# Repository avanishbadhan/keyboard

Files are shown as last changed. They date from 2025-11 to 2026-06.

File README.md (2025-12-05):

This project is a modular wired keyboard, consisting of a 75% keyboard with an attachable macropad. 
I made this project as a way to learn a variety of things including Schematic and PCB design, as it was my first time working with these; and also to practice some CAD. I have always wanted to know how keyboards work in general, as I use them every single day, and thought this might be a great way to learn, given the opportunity from Hack Club's Blueprint to bring my ideas to life.
Here are some images of CAD and PCB Design, BOM at the end.










|Item |Description |Quantity|Unit Price ($)|Total Price ($)|URL |Running Total ($ with Tax)|
|---|---|---|---|---|---|---|
|SOD-123 Switch Diodes |Switch Diodes (100pcs)|1 |1.28 |1.28 |https://www.aliexpress.us/item/3256807350544438.html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 |1.28 |
|Holy Panda Tactile Switches |MX Switches (110pcs)  |1 |33.3 |33.3 |https://www.aliexpress.us/item/3256805924985540.html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|34.58 |
|PJ-320D Headphone Jack |TRRS Jack (5pcs) |1 |1.04 |1.04 |https://www.aliexpress.us/item/3256808202284065.html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 |35.62 |
|Aux Stereo Cable |TRRS Cable |1 |3.58 |3.58 |https://www.aliexpress.us/item/3256805456527650.html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 |39.2 |
|Nice!Nano V2 Compatible Devboard |Devboard |1 |2.89 |2.89 |https://www.aliexpress.us/item/3256809330366531.html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 |42.09 |
|Arduino ProMicro Compatible Devboard|Devboard |1 |6.23 |6.23 |https://www.aliexpress.us/item/3256805885300100.html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 |48.32 |
|Keycaps |MX Keycaps (123pcs) |1 |11.33 |11.33 |https://www.aliexpress.us/item/3256808975886837.html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|59.65 |
|Solder Paste |Solder Paste (2pcs) |1 |8.11 |8.11 |https://www.aliexpress.us/item/3256806722346427.html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 |67.76 |
|Mounted Snap-In MX Stabilizers |MX Stabilizers |2 |3.88 |7.76 |https://www.aliexpress.us/item/3256808413621831.html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 |75.52 |
|M2 22mm Countersunk Screws |Screws (20pcs) |1 |2.02 |2.02 |https://www.aliexpress.us/item/3256808624582928.html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 |77.54 |
|Keyboard Gasket Foam Strip |Gasket Foam (20pcs) |1 |4.59 |4.59 |https://www.aliexpress.us/item/3256804614353215.html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 |82.13 |

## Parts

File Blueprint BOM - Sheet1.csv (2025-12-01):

Item | Description | Quantity | Unit Price ($) | Total Price ($) | URL | Running Total ($ with Tax)
SOD-123 Switch Diodes | Switch Diodes (100pcs) | 1 | 1.28 | 1.28 | https://www.aliexpress.us/item/3256807350544438.html?mp=1 | 1.28
Holy Panda Tactile Switches | MX Switches (110pcs) | 1 | 33.3 | 33.3 | https://www.aliexpress.us/item/3256805924985540.html?mp=1 | 34.58
PJ-320D Headphone Jack | TRRS Jack (5pcs) | 1 | 1.04 | 1.04 | https://www.aliexpress.us/item/3256808202284065.html?mp=1 | 35.62
Aux Stereo Cable | TRRS Cable | 1 | 3.58 | 3.58 | https://www.aliexpress.us/item/3256805456527650.html?mp=1 | 39.2
Nice!Nano V2 Compatible Devboard | Devboard | 1 | 2.89 | 2.89 | https://www.aliexpress.us/item/3256809330366531.html?mp=1 | 42.09
Arduino ProMicro Compatible Devboard | Devboard | 1 | 6.23 | 6.23 | https://www.aliexpress.us/item/3256805885300100.html?mp=1 | 48.32
Keycaps | MX Keycaps (123pcs) | 1 | 11.33 | 11.33 | https://www.aliexpress.us/item/3256808975886837.html?mp=1 | 59.65
Solder Paste | Solder Paste (2pcs) | 1 | 8.11 | 8.11 | https://www.aliexpress.us/item/3256806722346427.html?mp=1 | 67.76
Mounted Snap-In MX Stabilizers | MX Stabilizers | 2 | 3.88 | 7.76 | https://www.aliexpress.us/item/3256808413621831.html?mp=1 | 75.52
M2 22mm Countersunk Screws | Screws (20pcs) | 1 | 2.02 | 2.02 | https://www.aliexpress.us/item/3256808624582928.html?mp=1 | 77.54
Keyboard Gasket Foam Strip | Gasket Foam (20pcs) | 1 | 4.59 | 4.59 | https://www.aliexpress.us/item/3256804614353215.html?mp=1 | 82.13

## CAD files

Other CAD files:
75% keyboard/Keyboard.iam
75% keyboard/Keyboard_Case.ipt
75% keyboard/Keyboard_PCB.ipt
75% keyboard/Keyboard_Plate.ipt
75% keyboard/Keyboard_Tray.ipt

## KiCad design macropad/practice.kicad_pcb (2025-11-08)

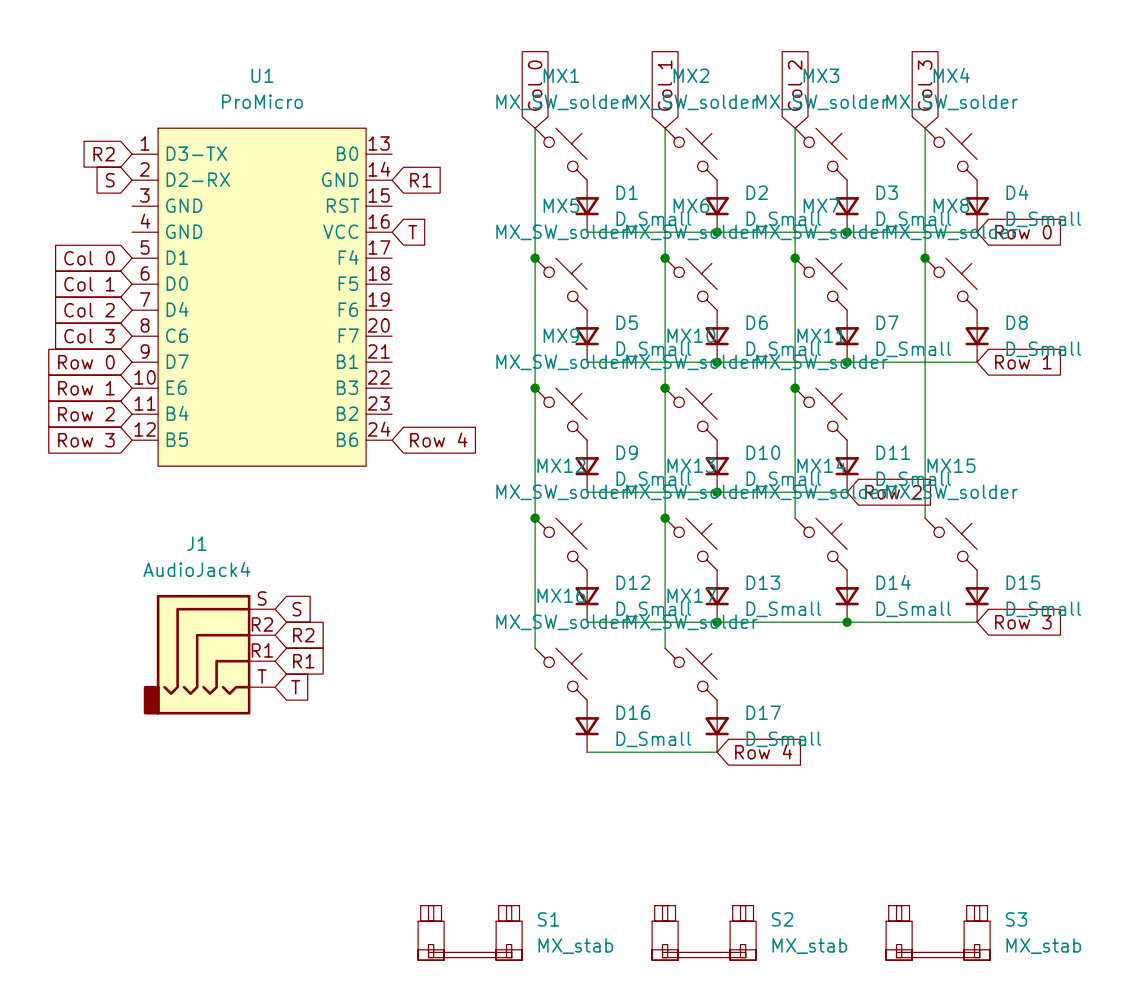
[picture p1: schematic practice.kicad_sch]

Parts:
D1, D2, D3, D4, D5, D6, D7, D8, D9, D10, D11, D12, D13, D14, D15, D16, D17: D_Small; D_SOD-123
J1: AudioJack4; Jack_3.5mm_PJ320D_Horizontal
MX1, MX2, MX3, MX4, MX5, MX6, MX7, MX8, MX9, MX10, MX11, MX12, MX13, MX14, MX15, MX16, MX17: MX_SW_solder; SW_MX_1u
S1, S2, S3: MX_stab; STAB_MX_2u
U1: ProMicro; ProMicro_USBup

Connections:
Col 0: MX1.1, MX5.1, MX9.1, MX12.1, MX16.1, U1.5 (D1)
Col 1: MX2.1, MX6.1, MX10.1, MX13.1, MX17.1, U1.6 (D0)
Col 2: MX3.1, MX7.1, MX11.1, MX14.1, U1.7 (D4)
Col 3: MX4.1, MX8.1, MX15.1, U1.8 (C6)
unnamed: D1.2 (A), MX1.2
unnamed: D2.2 (A), MX2.2
unnamed: D3.2 (A), MX3.2
unnamed: D4.2 (A), MX4.2
unnamed: D5.2 (A), MX5.2
unnamed: D6.2 (A), MX6.2
unnamed: D7.2 (A), MX7.2
unnamed: D8.2 (A), MX8.2
unnamed: D9.2 (A), MX9.2
unnamed: D10.2 (A), MX10.2
unnamed: D11.2 (A), MX11.2
unnamed: D12.2 (A), MX12.2
unnamed: D13.2 (A), MX13.2
unnamed: D14.2 (A), MX14.2
unnamed: D15.2 (A), MX15.2
unnamed: D16.2 (A), MX16.2
unnamed: D17.2 (A), MX17.2
R1: J1.R1, U1.14 (GND)
R2: J1.R2, U1.1 (D3-TX)
Row 0: D1.1 (K), D2.1 (K), D3.1 (K), D4.1 (K), U1.9 (D7)
Row 1: D5.1 (K), D6.1 (K), D7.1 (K), D8.1 (K), U1.10 (E6)
Row 2: D9.1 (K), D10.1 (K), D11.1 (K), U1.11 (B4)
Row 3: D12.1 (K), D13.1 (K), D14.1 (K), D15.1 (K), U1.12 (B5)
Row 4: D16.1 (K), D17.1 (K), U1.24 (B6)
S: J1.S, U1.2 (D2-RX)
T: J1.T, U1.16 (VCC)

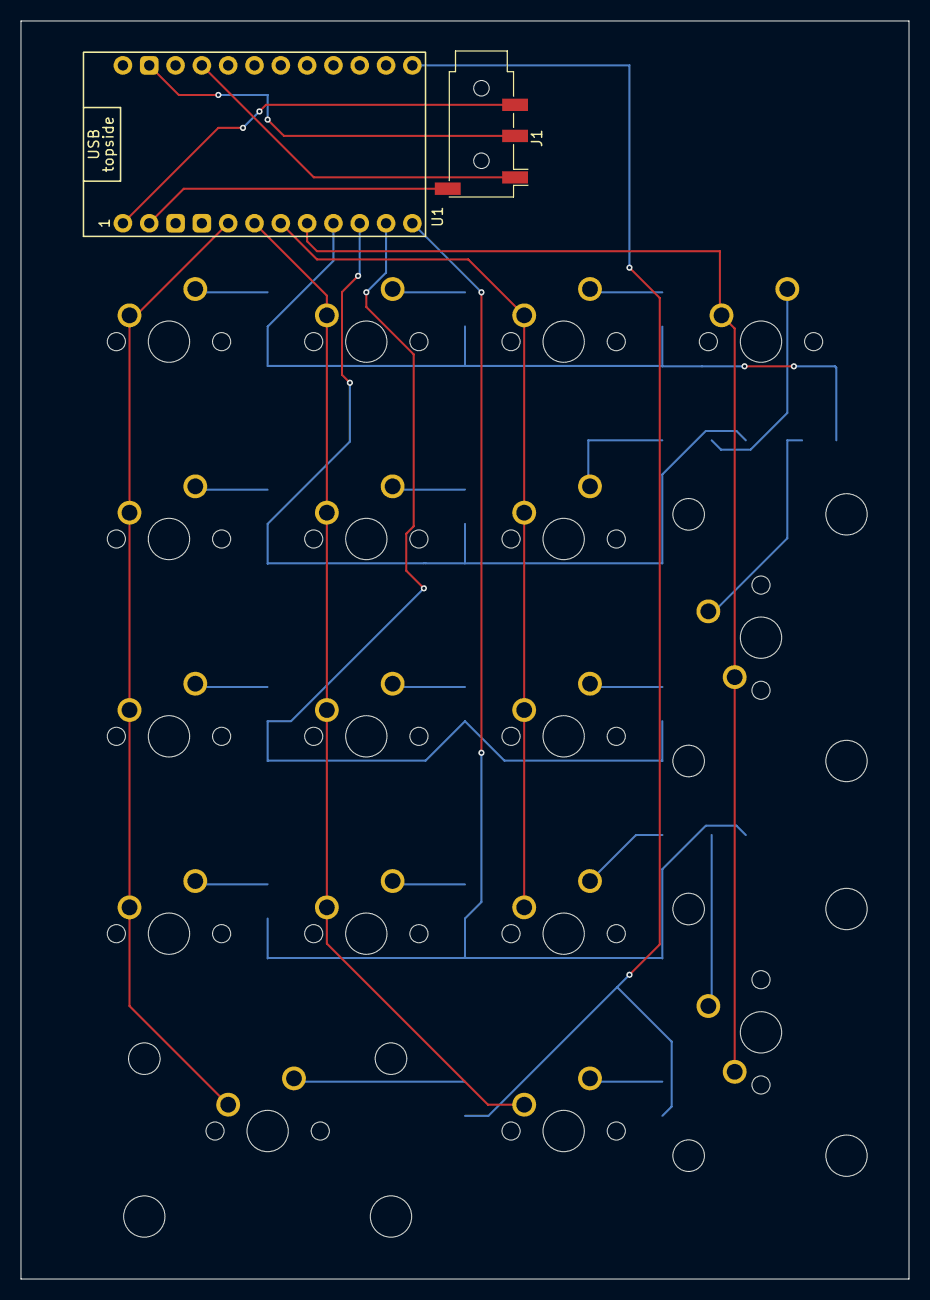
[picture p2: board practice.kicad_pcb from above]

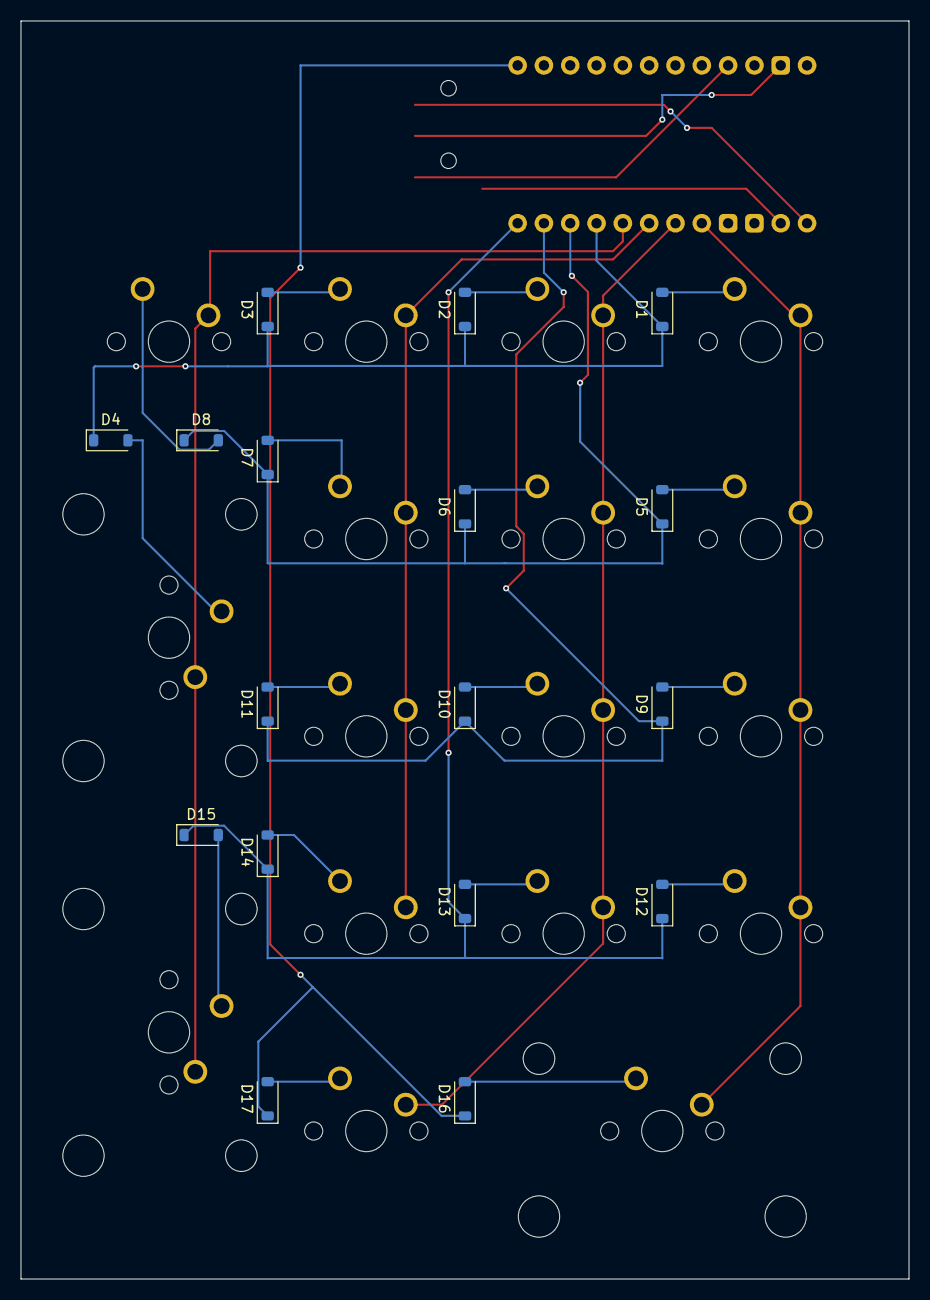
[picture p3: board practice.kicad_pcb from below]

Board: 2 copper layers, 85.7 x 121.4 mm, 39 parts (17 on the bottom side), 30 nets.

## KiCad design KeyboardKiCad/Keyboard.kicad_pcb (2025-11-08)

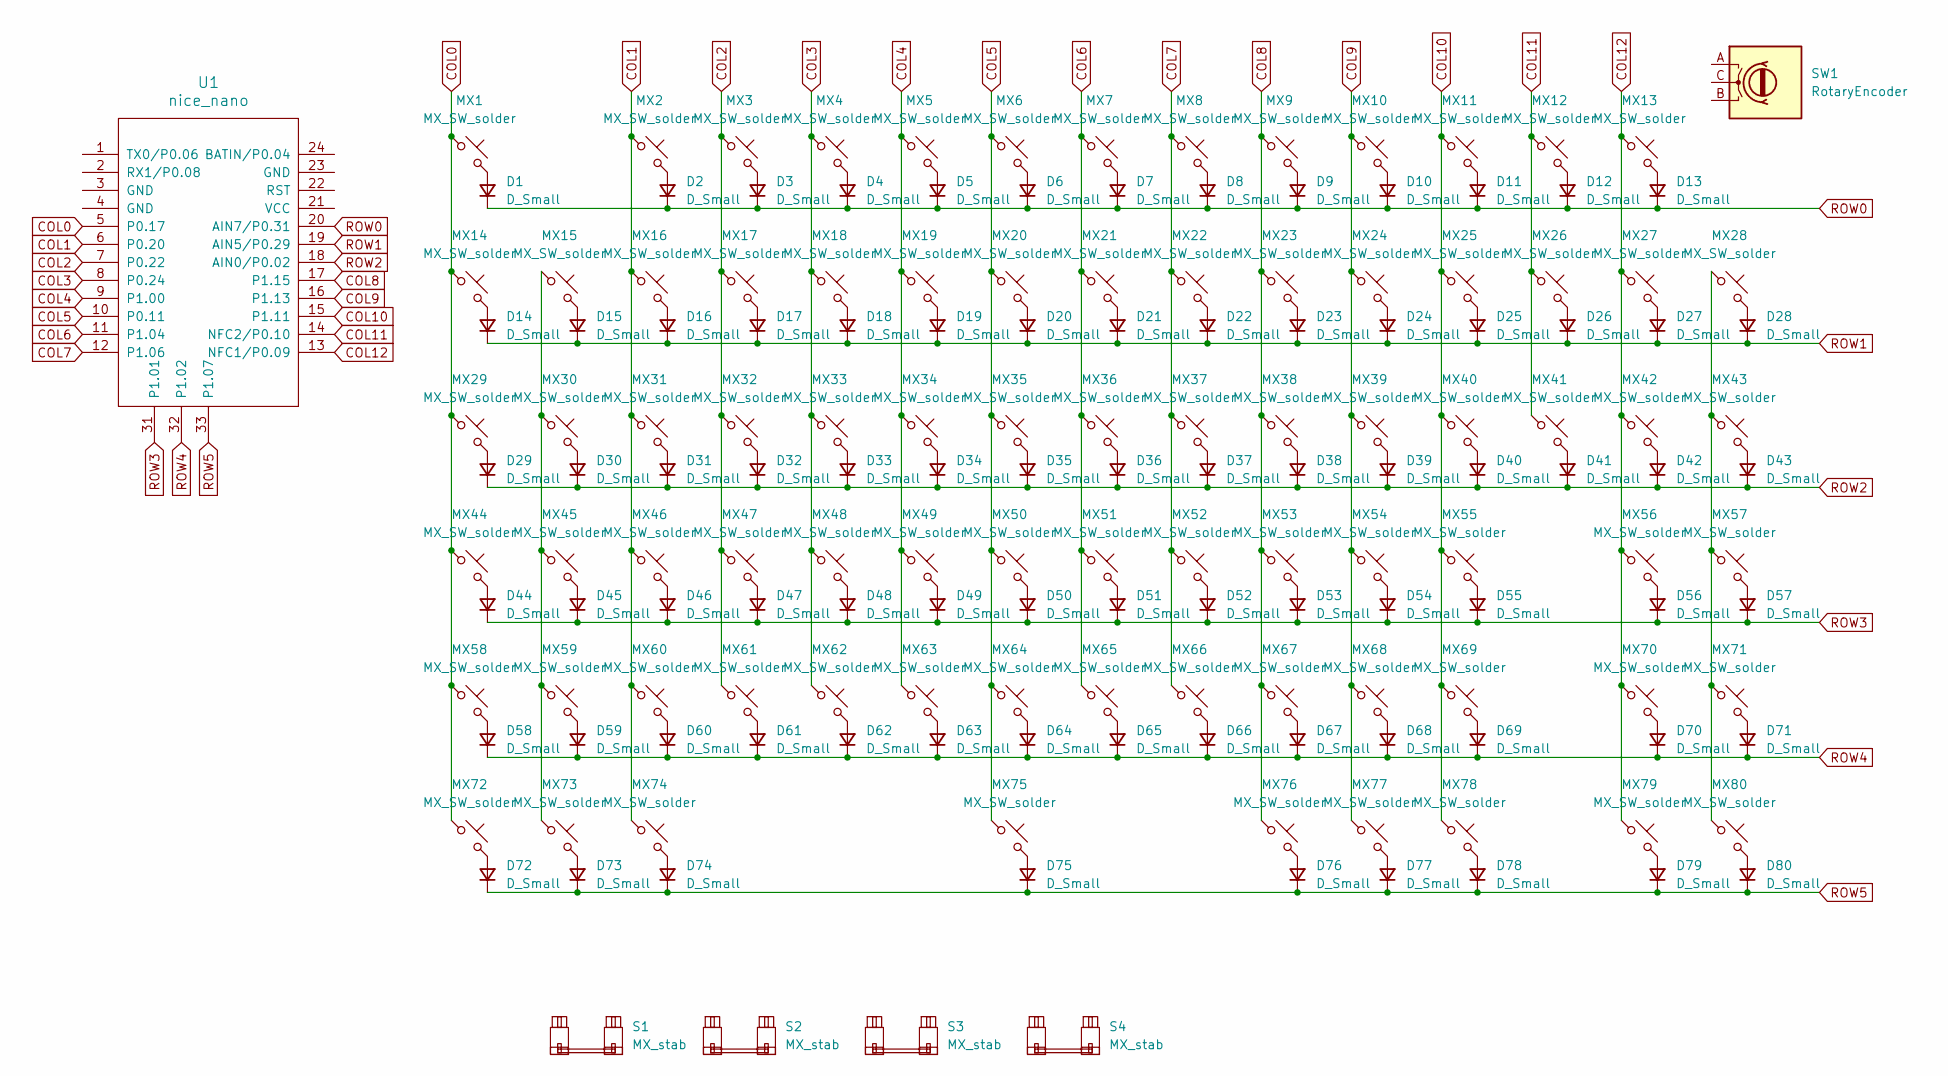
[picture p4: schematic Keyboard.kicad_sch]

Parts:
D1, D2, D3, D4, D5, D6, D7, D8, D9, D10, D11, D12, D13, D14, D15, D16, D17, D18, D19, D20, D21, D22, D23, D24, D25, D26, D27, D28, D29, D30, D31, D32, D33, D34, D35, D36, D37, D38, D39, D40, D41, D42, D43, D44, D45, D46, D47, D48, D49, D50, D51, D52, D53, D54, D55, D56, D57, D58, D59, D60, D61, D62, D63, D64, D65, D66, D67, D68, D69, D70, D71, D72, D73, D74, D75, D76, D77, D78, D79, D80: D_Small; D_SOD-123
MX1, MX2, MX3, MX4, MX5, MX6, MX7, MX8, MX9, MX10, MX11, MX12, MX13, MX14, MX15, MX16, MX17, MX18, MX19, MX20, MX21, MX22, MX23, MX24, MX25, MX26, MX27, MX28, MX30, MX31, MX32, MX33, MX34, MX35, MX36, MX37, MX38, MX39, MX40, MX41, MX43, MX45, MX46, MX47, MX48, MX49, MX50, MX51, MX52, MX53, MX54, MX55, MX56, MX57, MX58, MX59, MX60, MX61, MX62, MX63, MX64, MX65, MX66, MX67, MX68, MX70, MX71, MX75, MX78, MX79, MX80: MX_SW_solder; SW_MX_1u
MX29, MX42: MX_SW_solder; SW_MX_1.5u
MX44, MX69: MX_SW_solder; SW_MX_1.75u
MX72, MX73, MX74, MX76, MX77: MX_SW_solder; SW_MX_1.25u
S1: MX_stab; STAB_MX_P_2u
S2, S3: MX_stab; STAB_MX_P_2.25u
S4: MX_stab; STAB_MX_P_6.25u
SW1: RotaryEncoder; Bourns-PEC11R-4220F-S0024-0-0-0
U1: nice_nano; nice_nano_AH_Reversible

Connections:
COL0: MX1.1, MX14.1, MX29.1, MX44.1, MX58.1, MX72.1, U1.5 (P0.17)
COL1: MX2.1, MX16.1, MX31.1, MX46.1, MX60.1, MX74.1, U1.6 (P0.20)
COL2: MX3.1, MX17.1, MX32.1, MX47.1, MX61.1, U1.7 (P0.22)
COL3: MX4.1, MX18.1, MX33.1, MX48.1, MX62.1, U1.8 (P0.24)
COL4: MX5.1, MX19.1, MX34.1, MX49.1, MX63.1, U1.9 (P1.00)
COL5: MX6.1, MX20.1, MX35.1, MX50.1, MX64.1, MX75.1, U1.10 (P0.11)
COL6: MX7.1, MX21.1, MX36.1, MX51.1, MX65.1, U1.11 (P1.04)
COL7: MX8.1, MX22.1, MX37.1, MX52.1, MX66.1, U1.12 (P1.06)
COL8: MX9.1, MX23.1, MX38.1, MX53.1, MX67.1, MX76.1, U1.17 (P1.15)
COL9: MX10.1, MX24.1, MX39.1, MX54.1, MX68.1, MX77.1, U1.16 (P1.13)
COL10: MX11.1, MX25.1, MX40.1, MX55.1, MX69.1, MX78.1, U1.15 (P1.11)
COL11: MX12.1, MX26.1, MX41.1, U1.14 (NFC2/P0.10)
COL12: MX13.1, MX27.1, MX42.1, MX56.1, MX70.1, MX79.1, U1.13 (NFC1/P0.09)
unnamed: D1.2 (A), MX1.2
unnamed: D2.2 (A), MX2.2
unnamed: D3.2 (A), MX3.2
unnamed: D4.2 (A), MX4.2
unnamed: D5.2 (A), MX5.2
unnamed: D6.2 (A), MX6.2
unnamed: D7.2 (A), MX7.2
unnamed: D8.2 (A), MX8.2
unnamed: D9.2 (A), MX9.2
unnamed: D10.2 (A), MX10.2
unnamed: D11.2 (A), MX11.2
unnamed: D12.2 (A), MX12.2
unnamed: D13.2 (A), MX13.2
unnamed: D14.2 (A), MX14.2
unnamed: D15.2 (A), MX15.2
unnamed: D16.2 (A), MX16.2
unnamed: D17.2 (A), MX17.2
unnamed: D18.2 (A), MX18.2
unnamed: D19.2 (A), MX19.2
unnamed: D20.2 (A), MX20.2
unnamed: D21.2 (A), MX21.2
unnamed: D22.2 (A), MX22.2
unnamed: D23.2 (A), MX23.2
unnamed: D24.2 (A), MX24.2
unnamed: D25.2 (A), MX25.2
unnamed: D26.2 (A), MX26.2
unnamed: D27.2 (A), MX27.2
unnamed: D28.2 (A), MX28.2
unnamed: D29.2 (A), MX29.2
unnamed: D30.2 (A), MX30.2
unnamed: D31.2 (A), MX31.2
unnamed: D32.2 (A), MX32.2
unnamed: D33.2 (A), MX33.2
unnamed: D34.2 (A), MX34.2
unnamed: D35.2 (A), MX35.2
unnamed: D36.2 (A), MX36.2
unnamed: D37.2 (A), MX37.2
unnamed: D38.2 (A), MX38.2
unnamed: D39.2 (A), MX39.2
unnamed: D40.2 (A), MX40.2
unnamed: D41.2 (A), MX41.2
unnamed: D42.2 (A), MX42.2
unnamed: D43.2 (A), MX43.2
unnamed: D44.2 (A), MX44.2
unnamed: D45.2 (A), MX45.2
unnamed: D46.2 (A), MX46.2
unnamed: D47.2 (A), MX47.2
unnamed: D48.2 (A), MX48.2
unnamed: D49.2 (A), MX49.2
unnamed: D50.2 (A), MX50.2
unnamed: D51.2 (A), MX51.2
unnamed: D52.2 (A), MX52.2
unnamed: D53.2 (A), MX53.2
unnamed: D54.2 (A), MX54.2
unnamed: D55.2 (A), MX55.2
unnamed: D56.2 (A), MX56.2
unnamed: D57.2 (A), MX57.2
unnamed: D58.2 (A), MX58.2
unnamed: D59.2 (A), MX59.2
unnamed: D60.2 (A), MX60.2
unnamed: D61.2 (A), MX61.2
unnamed: D62.2 (A), MX62.2
unnamed: D63.2 (A), MX63.2
unnamed: D64.2 (A), MX64.2
unnamed: D65.2 (A), MX65.2
unnamed: D66.2 (A), MX66.2
unnamed: D67.2 (A), MX67.2
unnamed: D68.2 (A), MX68.2
unnamed: D69.2 (A), MX69.2
unnamed: D70.2 (A), MX70.2
unnamed: D71.2 (A), MX71.2
unnamed: D72.2 (A), MX72.2
unnamed: D73.2 (A), MX73.2
unnamed: D74.2 (A), MX74.2
unnamed: D75.2 (A), MX75.2
unnamed: D76.2 (A), MX76.2
unnamed: D77.2 (A), MX77.2
unnamed: D78.2 (A), MX78.2
unnamed: D79.2 (A), MX79.2
unnamed: D80.2 (A), MX80.2
unnamed: MX15.1, MX30.1, MX45.1, MX59.1, MX73.1
unnamed: MX28.1, MX43.1, MX57.1, MX71.1, MX80.1
ROW0: D1.1 (K), D2.1 (K), D3.1 (K), D4.1 (K), D5.1 (K), D6.1 (K), D7.1 (K), D8.1 (K), D9.1 (K), D10.1 (K), D11.1 (K), D12.1 (K), D13.1 (K), U1.20 (AIN7/P0.31)
ROW1: D14.1 (K), D15.1 (K), D16.1 (K), D17.1 (K), D18.1 (K), D19.1 (K), D20.1 (K), D21.1 (K), D22.1 (K), D23.1 (K), D24.1 (K), D25.1 (K), D26.1 (K), D27.1 (K), D28.1 (K), U1.19 (AIN5/P0.29)
ROW2: D29.1 (K), D30.1 (K), D31.1 (K), D32.1 (K), D33.1 (K), D34.1 (K), D35.1 (K), D36.1 (K), D37.1 (K), D38.1 (K), D39.1 (K), D40.1 (K), D41.1 (K), D42.1 (K), D43.1 (K), U1.18 (AIN0/P0.02)
ROW3: D44.1 (K), D45.1 (K), D46.1 (K), D47.1 (K), D48.1 (K), D49.1 (K), D50.1 (K), D51.1 (K), D52.1 (K), D53.1 (K), D54.1 (K), D55.1 (K), D56.1 (K), D57.1 (K), U1.31 (P1.01)
ROW4: D58.1 (K), D59.1 (K), D60.1 (K), D61.1 (K), D62.1 (K), D63.1 (K), D64.1 (K), D65.1 (K), D66.1 (K), D67.1 (K), D68.1 (K), D69.1 (K), D70.1 (K), D71.1 (K), U1.32 (P1.02)
ROW5: D72.1 (K), D73.1 (K), D74.1 (K), D75.1 (K), D76.1 (K), D77.1 (K), D78.1 (K), D79.1 (K), D80.1 (K), U1.33 (P1.07)

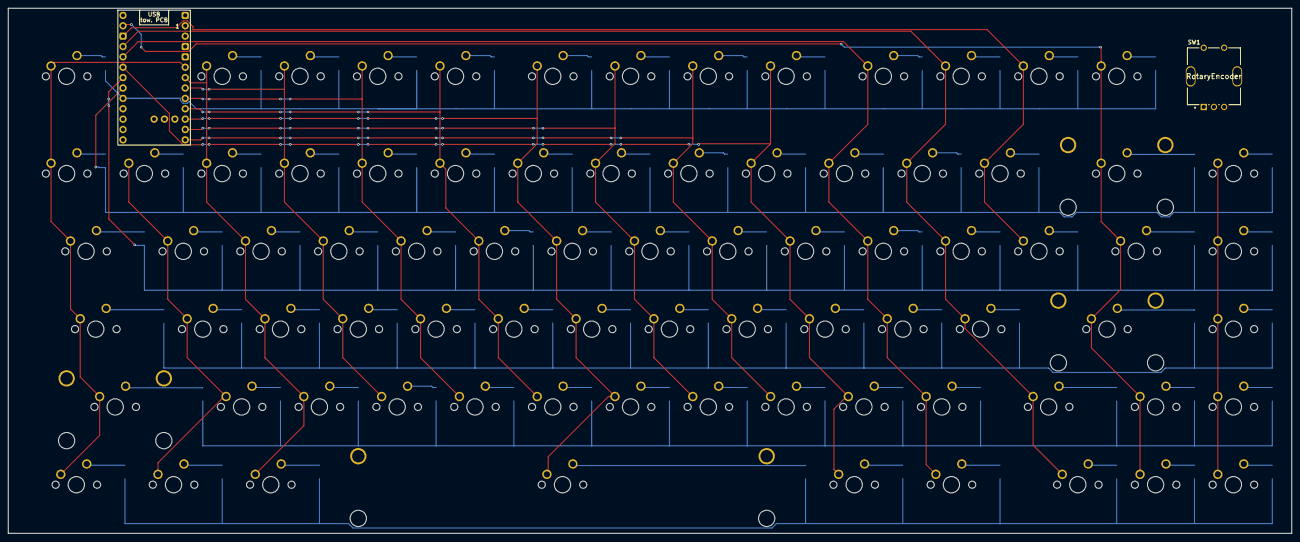
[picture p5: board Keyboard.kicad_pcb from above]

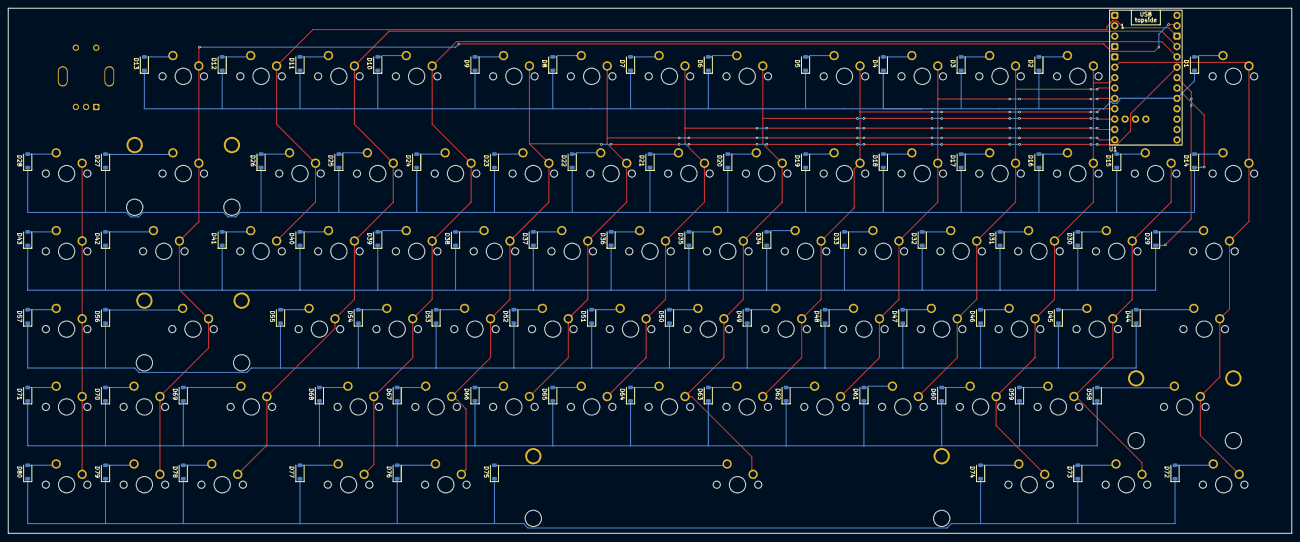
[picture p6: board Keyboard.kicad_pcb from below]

Board: 2 copper layers, 314.3 x 128.6 mm, 166 parts (81 on the bottom side), 101 nets.

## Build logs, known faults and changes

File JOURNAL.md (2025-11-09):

<!--
  ===================    !!READ THIS NOTICE!!   ====================
  DO NOT edit this file manually. Your changes WILL BE OVERWRITTEN!
  This journal is auto generated and updated by Hack Club Blueprint.
  To edit this file, please edit your journal entries on Blueprint.
  ==================================================================
-->

## 10/26/2025 - designed a schematic and pcb  

started with keyboard layout on keyboard layout editor, designed a prototype schematic and pcb for a 75% keyboard on kicad using diodes. needs rework to find placement for microcontroller. 


## 10/28/2025 - wired up the pcb, switched to nice!nano  

Wired up the PCB, front and back, connecting the diodes and switches, to the nice!nano.
Made some fixes, may need some more or rework, many design rule errors. 
Had to fix schematic rows and columns due to mistakes, overlapping wiring.



## 11/3/2025 - created schematic and pcb for number pad  

I created the schematic and pcb design for the number pad macropad I plan to have on the side. I wanted this to be detachable from the main keyboard as I do not use it often. This PCB runs without errors, and I moved to this as it gave me a good start to KiCad as I am new to the software and faced some issues starting off with a big PCB.



## 11/6/2025 - 3d components and rotary encoder  

I added 3d components such as all the key switches onto both pcbs. I added a rotary encoder on the top right of my 75% keyboard to control volume. Was missing STAB keys on the macropad which I had to fix up. Will need to make both microcontrollers match.


## 11/8/2025 - final touches  

Wrapped up both halves(keyboard + macropad) with a TRRS jack on both to connect them physically. 75% keyboard uses nice!nano and macropad uses pro micro. I took some time figuring out how to get the TRRS and understand how it works. I did not have space to include both the rotary encoder and TRRS jack on the main keyboard, so I ended up scrapping the rotary encoder for a simpler design, and the ability to connect both halves. Design rules all pass, will need to create case next.


## 11/9/2025 - case  

I created a 2 part case on Autodesk Inventor, imported case and pcb, and created an assembly. I spent a bunch of time on CAD and troubleshooting misaligned switch holes. I still need to add holes for mounting, and there is a mismatch between pcb and plate for the stabilizer mounting holes, which I need to fix. 


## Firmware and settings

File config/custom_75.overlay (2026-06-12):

/ {
    chosen {
        zmk,kscan = &kscan0;
    };

    kscan0: kscan_composite {
        compatible = "zmk,kscan-gpio-matrix";
        label = "KSCAN";
        diode-direction = "col2row";

        row-gpios
            = <&pro_micro 14 (GPIO_ACTIVE_HIGH | GPIO_PULL_DOWN)> // ROW0
            , <&pro_micro 15 (GPIO_ACTIVE_HIGH | GPIO_PULL_DOWN)> // ROW1
            , <&pro_micro 18 (GPIO_ACTIVE_HIGH | GPIO_PULL_DOWN)> // ROW2
            , <&pro_micro 19 (GPIO_ACTIVE_HIGH | GPIO_PULL_DOWN)> // ROW3
            , <&pro_micro 20 (GPIO_ACTIVE_HIGH | GPIO_PULL_DOWN)> // ROW4
            , <&pro_micro 21 (GPIO_ACTIVE_HIGH | GPIO_PULL_DOWN)> // ROW5
            ;

        col-gpios
            = <&pro_micro 1  GPIO_ACTIVE_HIGH> // COL0
            , <&pro_micro 2  GPIO_ACTIVE_HIGH> // COL1
            , <&pro_micro 3  GPIO_ACTIVE_HIGH> // COL2
            , <&pro_micro 4  GPIO_ACTIVE_HIGH> // COL3
            , <&pro_micro 5  GPIO_ACTIVE_HIGH> // COL4
            , <&pro_micro 6  GPIO_ACTIVE_HIGH> // COL5
            , <&pro_micro 7  GPIO_ACTIVE_HIGH> // COL6
            , <&pro_micro 8  GPIO_ACTIVE_HIGH> // COL7
            , <&pro_micro 9  GPIO_ACTIVE_HIGH> // COL8
            , <&pro_micro 10 GPIO_ACTIVE_HIGH> // COL9
            , <&pro_micro 16 GPIO_ACTIVE_HIGH> // COL10
            , <&pro_micro 14 GPIO_ACTIVE_HIGH> // COL11
            , <&pro_micro 13 GPIO_ACTIVE_HIGH> // COL12
            ;
    };
};

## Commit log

2025-11-08 kicad project files
    [Keyboard.kicad_pcb, Keyboard.kicad_sch]
2025-11-08 project files
    [Keyboard.kicad_pcb, Keyboard.kicad_sch]
2025-11-08 75% keyboard and macropad
    [Keyboard.kicad_pcb, Keyboard.kicad_sch, practice.kicad_pcb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]
2025-11-08 kicad files
    [Keyboard.kicad_pcb, Keyboard.kicad_sch, practice.kicad_pcb]
2025-11-09 kicad + CAD files
    CAD was created using Autodesk Inventor
    [Keyboard.iam, Keyboard.kicad_pcb, Keyboard_Case.ipt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]
2025-12-05 KiCad files to repo
    [Keyboard.kicad_pcb, Keyboard.kicad_sch]
